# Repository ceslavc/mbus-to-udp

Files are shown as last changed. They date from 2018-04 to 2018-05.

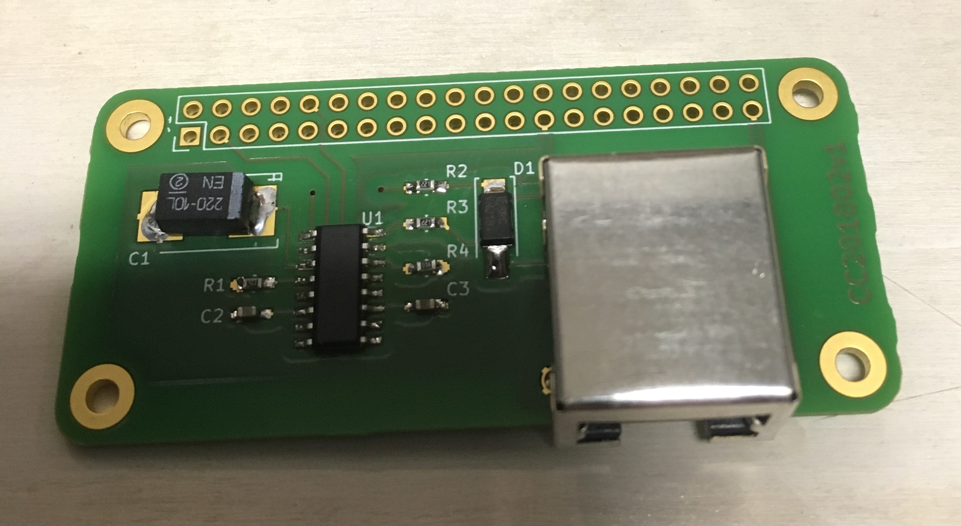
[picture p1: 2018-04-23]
pic/konverter.jpg

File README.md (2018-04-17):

# mbus-to-udp
A converter that connects to a Kamstrup smart power meter MBUS output, reads OBIS data and sends them as UDP

## Short description

This is a complete converter - circuit, pcb, housing and a software. It is made to be used with node-red server. A sample node is also included.

## Language note

As the unit is designed for Norwegian power grid there is more detailed description in the norwegian README. I will translate if there will be interest for it.

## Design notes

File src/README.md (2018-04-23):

# Installation

## Preparations

Set up and start Raspberry Pi Zero. The SD card image may be downloaded from https://www.raspberrypi.org/downloads/raspbian/. Here you may also find the instructions.

Update the system and install ```gcc``` and ```make```.

After everything is up and running do following:  

Edit the ```/boot/config.txt``` file. Add following at the end of the file:
```
enable_uart=1
dtoverlay=pi3-miniuart-bt
```

Edit the ```/boot/cmdline.txt``` file. Remove any mentions of serial port ```ttyAMA0```. It looks someting like this:
```
xxxxxxx xxxxxxxx console=ttyAMA0,115200 yyyyyyy yyyyyyy
```

## Security

A good practice is to replace default user ```pi``` with a new one. Make sure that the new user has administration rights before removing ```pi```.

## Network

The system does not require a static ip address. It may be a usefull for remote access and administration.

## Installation

Download or clone the source code, ```mbustoudp.service``` and ```Makefile``` 

Use regular ```make``` commands to build and install the utility.

Before installing you must edit the ```mbustoudp.service``` file. Replace ```ip_address``` and ```port``` with address and port of your Node Red server.

```sudo make install``` will copy files to their locations and starts and enables the service. Must be run as root.

Service will be stopped, disabled and all the files will be removed with ```sudo make clean```

## What is working and what's not

The program is sending consumed power and voltage and current for all three phases.

It does not send reactive power nor the data that are coming every hour. It has not been tested with one phase meter. This will be changed in later version.

The choice of sending separate JSON for every value comes from early testing which did not catch all the data. I will test sending all the data in one JSON object.

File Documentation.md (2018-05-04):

# MBUS to UDP converter

## System decription
The converter consists of a interface card mounted on a Raspberry Pi Zero. Input is a stream of meter data on a MBUS interface. Output is a stream of JSON objects sent to a UDP port on a extern server running Node Red. Network connection is via RPi's internal wifi card. 
The converter card is supplied from the MBUS line, Raspbery Pi is sypplied from a separate 5V power supply.
RPi and converter card is connected via three pins in the GPIO header - 3,3V, UART RX and GND.

## The converter card
A MBUS interface IC NCN5150 needs a small number of external components to function. Connection to the smart meter is via standard ethernet cable (MBUS uses pins 1 and 2) through a RJ45 socket. The converter card has the same header pins as the Raspberry Pi. It is possible to connect all the 40 pins, but it is not required. Only three pins must be connected.

## Data stream from smart meter
This description is for Kamstrup smart meter, all the other meters should follow the same standard (see the NVE note).

There are two data blocks. One is sent every 10 seconds, one every hour.

Following data are pushed from the meter:

Nr|OBIS code|Object|Descrtiption|Unit|Scaler
--|---------|------|------------|----|------
1|1.1.0.2.129.255|OBIS List version identifier
2|1.1.0.0.5.255|GS1 number|Meter -ID (GIAI GS1 -16 digit )
3|1.1.96.1.1.255|Meter type|Visible string
4|1.1.1.7.0.255|P14|Active power from the grid|W|0
5|1.1.2.7.0.255|P23|Active power to the grid|W|0
6|1.1.3.7.0.255|Q12|Reactive power from the grid|var|0
7|1.1.4.7.0.255|Q34|Reactive power to the grid|var|0
8|1.1.31.7.0.255|IL1|Current phase 1|A|-2
9|1.1.51.7.0.255|IL2|Current phase 2|A|-2
10|1.1.71.7.0.255|IL3|Current phase 3|A|-2
11|1.1.32.7.0.255|UL1|Phase or line voltage 1|V|0
12|1.1.52.7.0.255|UL2|Phase or line voltage 2|V|0
13|1.1.72.7.0.255|UL3|Phase or line voltage 3|V|0
14|0.1.1.0.0.255|RTC|Clock and date
15|1.1.1.8.0.255|A14|Cumulative hourly active import energy|Wh|1
16|1.1.2.8.0.255|A23|Cumulative hourly active export energy|Wh|1
17|1.1.3.8.0.255|R12|Cumulative hourly reactive import energy|varh|1
18|1.1.4.8.0.255|R34|Cumulative hourly reactive export energy|varh|1

Data 1-13 are pushed every 10 seconds, 1-18 is pushed every hour

Data that are not present (if the meter is only one phase) are omitted. Voltage depends on type of grid connection (3 or 4 wire).

Example (from Kamstrup documentation)
```
7E A0E2 2B 21 13 239A E6E700
0F 00000000 0C07D0010106162100FF800001
0219
0A0E 4B616D73747275705F5630303031
0906 0101000005FF 0A10 35373036353637303030303030303030
0906 0101600101FF 0A12 303030303030303030303030303030303030
0906 0101010700FF 0600000000   
0906 0101020700FF 0600000000
0906 0101030700FF 0600000000
0906 0101040700FF 0600000000
0906 01011F0700FF 0600000000
0906 0101330700FF 0600000000
0906 0101470700FF 0600000000
0906 0101200700FF 120000
0906 0101340700FF 120000
0906 0101480700FF 120000
0906 0001010000FF 090C 07E1081003100005FF800000
0906 0101010800FF 0600000000
0906 0101020800FF 0600000000
0906 0101030800FF 0600000000
0906 0101040800FF 0600000000
C8867E
```
The interesting data start on line 7. Every data line starts with 0906, then the OBIS code and a data block. 

## JSON object

There is one object for every value received from the meter. I have choosen this way rather than sending all the data in one object. This way some data will be sent if there is a transmission error. Also the program may be also used for one-phase meters.

The object is defined as such:
```
data : (string)
value : (float value)
topic : "AMS"              
```
```data``` is a string, it identificates what kind of data is sent
ID|Obis code|Explanation
--|---------|-----------
power|P14|Power (W) consumed from the grid at the moment
powerto|P23|Power (W) delivered to the grid
rpower|Q12|Reactive power (var) consumed from the grid
rpowerto|Q34|Reactive power (var) delivered to the grid
pcons|A14|Cumulative consumed power (Wh)
pdelv|A23|Cumulative delivered power (Wh)
rpcons|R12|Cumulative consumed reactive power (varh)
rpdelv|R34|Cumulative delivered reactive power (varh)
amp1|IL1|Current phase 1 (A)
amp2|IL2|Current phase 2 (A)
amp3|IL3|Current phase 3 (A)
vol1|UL1|Voltage phase/line 1 (V)
vol2|UL2|Voltage phase/line 2 (V)
vol3|UL3|Voltage phase/line 3 (V)

```value``` is a float value

```topic``` is a string value "AMS" that allows node red to sort packets according to which device sent them. Effectively it is possible to use the same port and UDP node to receive data from several different devices.

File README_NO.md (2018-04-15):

# mbus-to-udp

## Innledning

Som alle andre her i landet fikk jeg en smart elmåler. Den heter Kamstrup. Siden loven gir meg rett til å se mine data, har netteieren sendt meg en gratis HAN modul og ønsket med lykke til med å se dataene.

NVE har valgt en M-BUS grensesnitt. De kunne ha valgt RS-232 eller ethernet men det hadde kanskje vært for enkelt.

MBUS ble opprinnelig laget for å samle data fra mange målere i et stor område. Den tåler lange avstander og dårlige kabler. Meningen er at måleren skal være en slave som svarer på forespørsler fra en master innsamlingsenhet. Implementeringen av MBUS i HAN modulen derimot er helt motsatt  - måleren en master som sender en strøm med data. 

Det jeg trengte var en slave mottaker som kunne konvertere MBUS til en signal som kan brukes.

## Systembeskrivelse

Mottakerkretsen sitter oppå en Raspberry Pi Zero W. Kobling til HAN modulen er via en vanlig nettverkskabel. Datastrøm blir konvertert fra MBUS 24-36V nivå til UART spenningsnivå (3,6V) som leveres fra RPi. Mottakerkretsen er strømforsynt fra MBUS linje. Raspberry Pi gjør nødvendig dekoding og sender data ut som UDP over trådløs nett (derfor RPi W modellen). I min tilfelle sendes data til en Node-Red server som tar seg av visualisering og videre styring.

## Prosjektkomponenter

* **kicad** - Skjema over mottakerkretsen, kretskort og komponentliste
* **stl** - Boks for konverter som monteres på en DIN skinne
* **src** - kildekode til program som tar mot, dekoder og sender data.
* **nodered** - eksempelnode for visning av brukt effekt, strøm og spenning

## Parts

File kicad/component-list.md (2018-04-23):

# List of components
*Farnell numbers are for reference*

Name|Component|Value|Package|Farnell nr.
----|---------|-----|-------|-----------
R1|SMD resistor|30k|0603|2447333
R2, R3|SMD resistor|220R|0603|2447298
R4|SMD resistor|100R|0603|2447227
C1|SMD Tantalum capacitor|220uF 10V|Case E|1754172
C2|SMD Capacitor|200nF 16V|0603|2496921
C3|SMD Capacitor|1uF 10V|0603|2332687
D1|TVS Diode|1SMA40CAT3G|DO-214AC|2533120
U1|M-BUS interface|NCN5150|SOIC16|2531193
J2|RJ45 socket|MOLEX  85505-51131||1560163

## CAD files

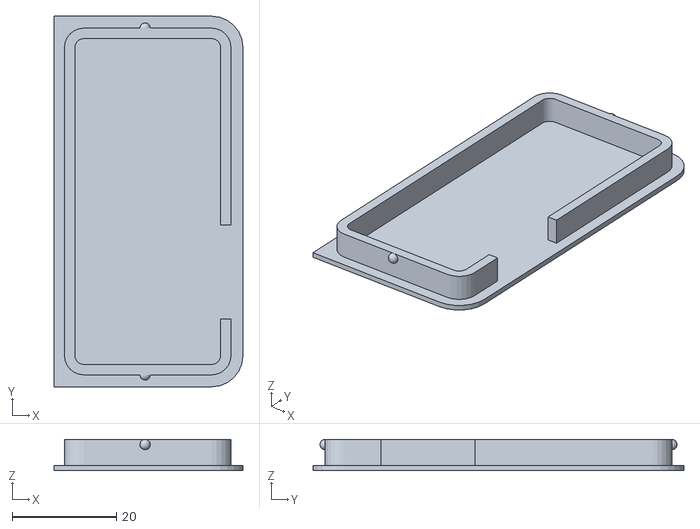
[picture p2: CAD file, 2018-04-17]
stl/mbus-to-udp_housing_lid.stl
36.2 x 71.0 x 6.00

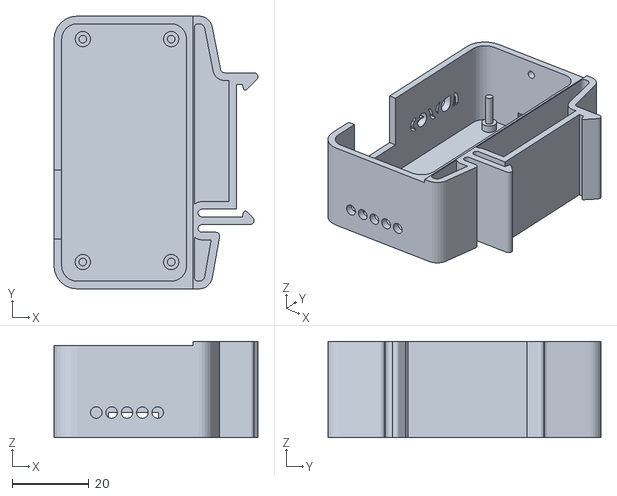
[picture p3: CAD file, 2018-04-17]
stl/mbus-to-udp_housing_DIN.stl
53.1 x 71.0 x 25.0

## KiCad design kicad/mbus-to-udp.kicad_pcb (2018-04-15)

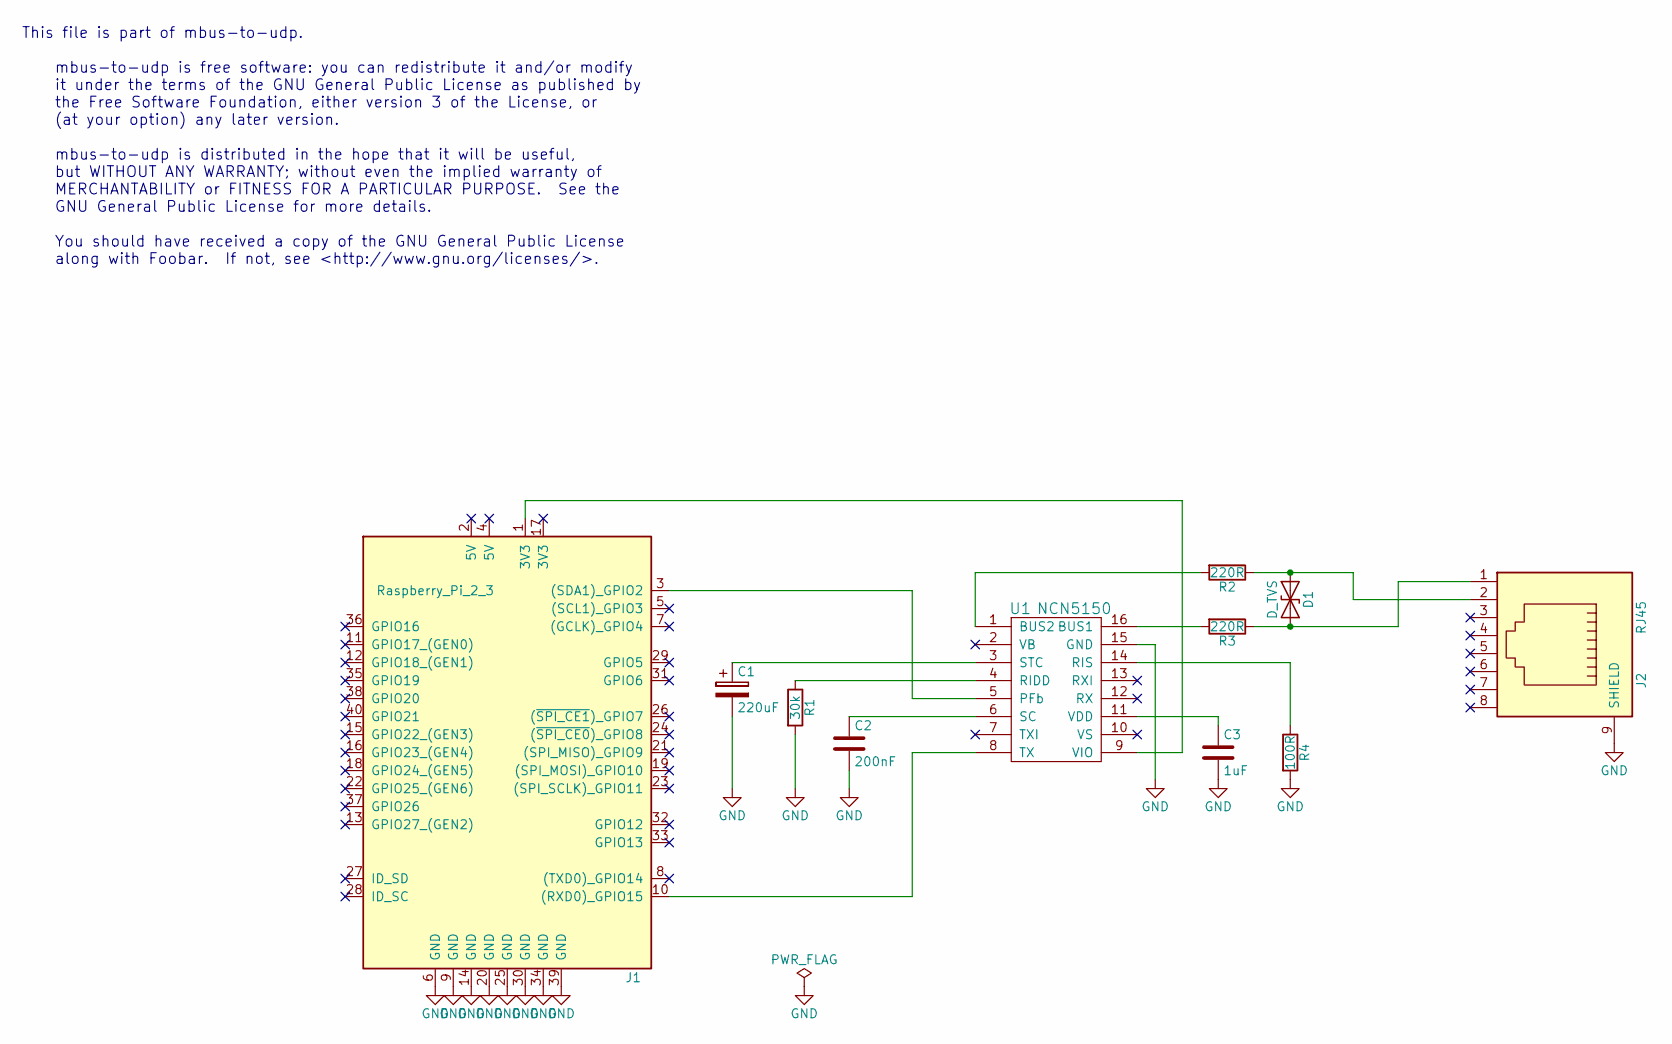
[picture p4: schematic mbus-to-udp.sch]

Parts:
C1: 220uF; CP_Tantalum_Case-E_EIA-7260-38_Hand
C2: 200nF; C_0603_HandSoldering
C3: 1uF; C_0603_HandSoldering
D1: D_TVS; D_SMA_Handsoldering
J1: Raspberry_Pi_2_3; Pin_Header_Straight_2x20_Pitch2.54mm
J2: RJ45; RJ45_8x
R1: 30k; R_0603_HandSoldering
R2, R3: 220R; R_0603_HandSoldering
R4: 100R; R_0603_HandSoldering
U1: NCN5150; SOIC-16_3.9x9.9mm_Pitch1.27mm

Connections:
GND: C1.2, C2.2, C3.2, J1.6 (GND), J1.9 (GND), J1.14 (GND), J1.20 (GND), J1.25 (GND), J1.30 (GND), J1.34 (GND), J1.39 (GND), J2.9 (SHIELD), R1.2, R4.2, U1.15 (GND)
unnamed: C1.1, U1.3 (STC)
unnamed: C2.1, U1.6 (SC)
unnamed: C3.1, U1.11 (VDD)
unnamed: D1.1 (A1), J2.2, R2.1
unnamed: D1.2 (A2), J2.1, R3.1
unnamed: J1.1 (3V3), U1.9 (VIO)
unnamed: J1.3 ((SDA1)_GPIO2), U1.5 (PFb)
unnamed: J1.10 ((RXD0)_GPIO15), U1.8 (TX)
unnamed: R1.1, U1.4 (RIDD)
unnamed: R2.2, U1.1 (BUS2)
unnamed: R3.2, U1.16 (BUS1)
unnamed: R4.1, U1.14 (RIS)

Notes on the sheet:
This file is part of mbus-to-udp. mbus-to-udp is free software: you can redistribute it and/or modify it under the terms of the GNU General Public License as published by the Free Software Foundation, either version 3 of the License, or (at your option) any later version. mbus-to-udp is distributed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

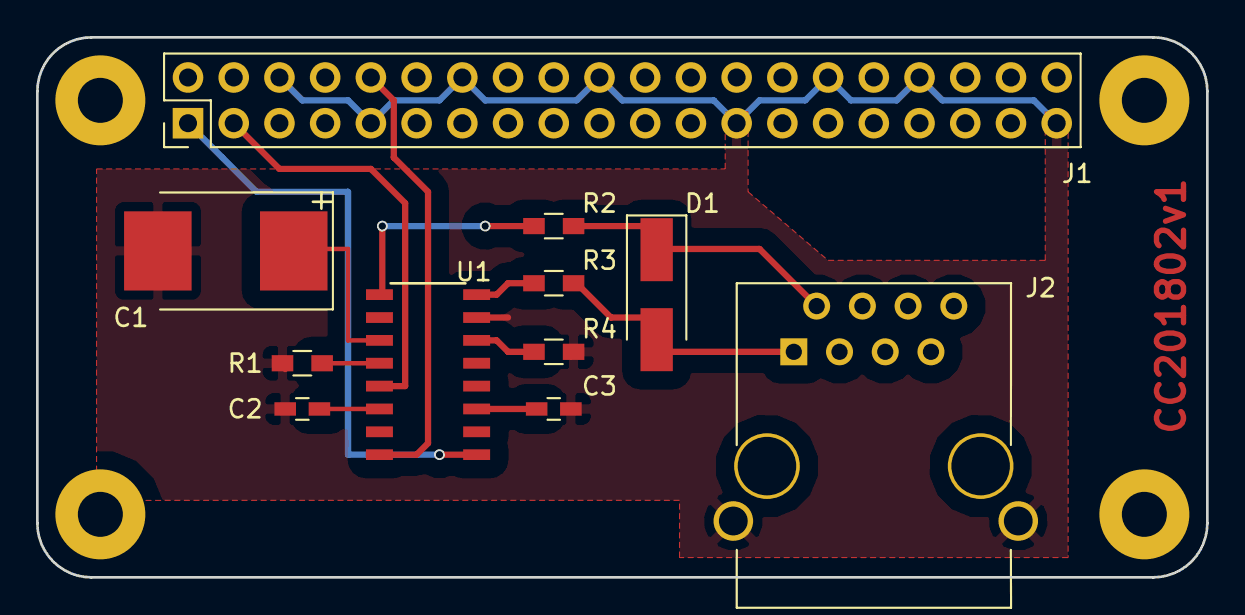
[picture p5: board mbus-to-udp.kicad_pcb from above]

Board: 2 copper layers, 65.0 x 30.0 mm, 11 parts (0 on the bottom side), 13 nets.

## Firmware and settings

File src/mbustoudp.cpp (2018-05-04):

/* 
MBUS to UDP converter v0.9
(c) 2018 Ceslav Czyz 

This file is part of mbus-to-udp.

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
*/
# include <stdio.h>
# include <stdlib.h>
# include <stdint.h>
# include <termios.h>
# include <fcntl.h>
# include <string.h>
# include <unistd.h>
# include <netdb.h>
# include <sys/socket.h>
# include <netinet/in.h>

struct termios gammel_uart;        		// structure to save the state of the serial port
int uart;                             	// serial port handle
char *port, *msg;						// filename of the serial port, string for the UDP message
int sockfd;         					// IP socket for UDP message
struct addrinfo *nodered;				// stucture to address the data receiver

// Print help text
void printhelp(void)
{
printf("Converter from MBUS to UDP\n");
printf("Usage:\n\tmbustoudp <parameter> <ip_address> <port>\n");
printf("\tMust be run as root due to serial port access rights\n");
printf("\tMake sure the firewall is open on receiver\n");
printf("Parameters:\n\t--help\tshow this text\n\t--mon\trun in monitor mode - show what is coming on serial port\n");
printf("\t--test\tsend a test JSON object\n");
return;
}


// reset the serial port to its original state

void reset_serial_port(void)
{
tcsetattr(uart, TCSANOW, &gammel_uart);
free(port);
free(msg);
close(uart);
}

// initialize and open serial port

int open_serial_port (void)
{
struct termios tattr;

// set the name of the serial port
port=(char*)malloc(16);
strcpy(port,"/dev/ttyAMA0");

// open serial port
uart = open(port,O_RDWR|O_NOCTTY);
if (uart==-1)
	{
	printf("Error opening port\n");
	exit(0);
	}

// save serial port state for recovery at exit
tcgetattr (uart,&gammel_uart);
atexit (reset_serial_port);

// copy serial port state for modificatiom
tcgetattr (uart,&tattr);

// modify serial port parameters
tattr.c_lflag &= ~(ICANON|ECHO|ECHOE|ISIG);
tattr.c_cflag |= CS8|CLOCAL|CREAD;
tattr.c_iflag = IGNPAR;
tattr.c_oflag = 0;
tattr.c_cc[VMIN] = 1;
tattr.c_cc[VTIME] = 0;
cfsetspeed(&tattr,B2400);

// clean the buffer 
tcflush(uart,TCIFLUSH);

// set new state
tcsetattr (uart,TCSANOW,&tattr);

return 0;
}

// initialize socket for UDP sending

int set_socket (char* ip, char* port)
{
struct addrinfo hints;
int status;

sockfd=socket(PF_INET, SOCK_DGRAM, IPPROTO_UDP);
if (sockfd == -1) 
    {
        printf("Error initializing socket\n");
        exit(1);
    }

memset(&hints, 0, sizeof hints);    
hints.ai_family = AF_UNSPEC;        
hints.ai_socktype = SOCK_DGRAM;
status = getaddrinfo(ip, port, &hints, &nodered);
if (status != 0) 
    {
        printf("Cannot open socket, is the IP address and port valid?\n");
        exit(1);
    }
return 0;
}

void sendjson(int ign, float scale, const char *data_id)
{
	int val;
	char c, cc;
	int i;
	for(i=0;i<ign;i++) read(uart,&c,1);
	read(uart,&cc,1);							//higher byte
	read(uart,&c,1);							//lower byte
	val=(cc*256+c)*scale;						//multiply and scale
	sprintf(msg,"{\"data\":\"%s\",\"value\":%d,\"topic\":\"AMS\"}",data_id,val);
	sendto(sockfd, msg, strlen(msg), 0, nodered->ai_addr, nodered->ai_addrlen);	
	return;
}


void transceive(void)
{
char c,c1,c2,c3,c4;
int n;
msg=(char*)malloc(64);

while (1) {
	read(uart, &c, 1);
	
	if (c==9) {
		read(uart, &c, 1);
		if (c==6) {					// 9,6 - OBIS code is following
			read(uart, &c1, 1);
			if (c1==1) {				//1 - all other except clock, but who cares about clock
				read(uart, &c2, 1);
					if (c2==1) {		// All codes have 1 here, just checking
						read(uart, &c3, 1);
						if (c3==1) {
							read(uart, &c4,1);						//ACTIVE power FROM grid, check next byte
							if (c4==7) sendjson(5,1,"power");		//power from grid
							else if (c4==8) sendjson(5,10,"pcons"); //cummulative consumed power
						}
						else if (c3==2) {
							read(uart, &c4,1);						//ACTIVE power TO grid, check next byte
							if (c4==7) sendjson(5,1,"powerto");		//power to grid
							else if (c4==8) sendjson(5,10,"pdelv"); 	//cummulative delivered power
						}
						else if (c3==3)  {
							read(uart, &c4,1);						//REACTIVE power FROM grid, check next byte
							if (c4==7) sendjson(5,1,"rpower");		//power from grid
							else if (c4==8) sendjson(5,10,"rpcons"); //cummulative consumed reactive power
						}
						else if (c3==4)  {
							read(uart, &c4,1);						//REACTIVE power TO grid, check next byte
							if (c4==7) sendjson(5,1,"rpowerto");		//power to grid
							else if (c4==8) sendjson(5,10,"rpdelv"); //cummulative delivered reactive power
						}
						else if (c3==31) sendjson(6,0.01,"amp1");	//current phase 1, divided by 100;
						else if (c3==51) sendjson(6,0.01,"amp2");	//current phase 2
						else if (c3==71) sendjson(6,0.01,"amp3");	//current phase 3
						else if (c3==32) sendjson(4,1,"vol1");		//voltage phase 1, no scaling
						else if (c3==52) sendjson(4,1,"vol2");		//voltage phase 2
						else if (c3==72) sendjson(4,1,"vol3");		//voltage phase 3
						}
					}	
				} 
			}
	}


return;
}

int main(int argc, char* argv[])
{
char c;

// Must be run as root due serial port ownership


// no parameters
if (argc==1) printf("No parameters, type 'mbustoudp --help' for help\n");

// one parameter - may be help or monitor
else if (argc==2) {
    if (!strcmp(argv[1],"--help")) printhelp();
    else if (!strcmp(argv[1],"--mon")) {
		if (getuid()) {printf("You must be root.\n"); return 0; } 
		open_serial_port();
		printf("Running in monitor mode, press ctrl-c to quit.\n");
		while (1) {
			read(uart,&c,1);
			printf("%c ",c);
		}
	}
	else if (!strcmp(argv[1],"--test")) {
		printf("Please provide ip address and port.\n");
		}
	else printf("Unknown parameter\n");
}

// two parameters, lets hope it is ip address and port
else if (argc==3) {
	if (getuid()) {printf("You must be root.\n"); return 0; } 
	set_socket(argv[1],argv[2]);
	open_serial_port();
	transceive();
}

else if ((argc==4) && (!strcmp(argv[1],"--test"))) {
	set_socket(argv[2],argv[3]);
	msg=(char*)malloc(64);
	sprintf(msg,"{\"data\":\"power\",\"value\":1342,\"scale\":0,\"topic\":\"AMS\"}");
	sendto(sockfd, msg, strlen(msg), 0, nodered->ai_addr, nodered->ai_addrlen);
	printf("Sendt single JSON object to address/port. Power node should show 1342W.\n");
	exit(0);
}

else printf("Unknown parameter\n");

return 0;
}

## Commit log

2018-04-15 Added kicad files and cleaned up the README files
    [mbus-to-udp.kicad_pcb, mbus-to-udp.sch]
2018-04-17 Added stl files
    [mbus-to-udp_housing_DIN.stl, mbus-to-udp_housing_lid.stl]
2018-04-18 Added Node Red sample node
